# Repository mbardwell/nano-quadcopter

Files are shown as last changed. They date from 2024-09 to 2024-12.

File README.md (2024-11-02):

# Nano Quadcopter Project

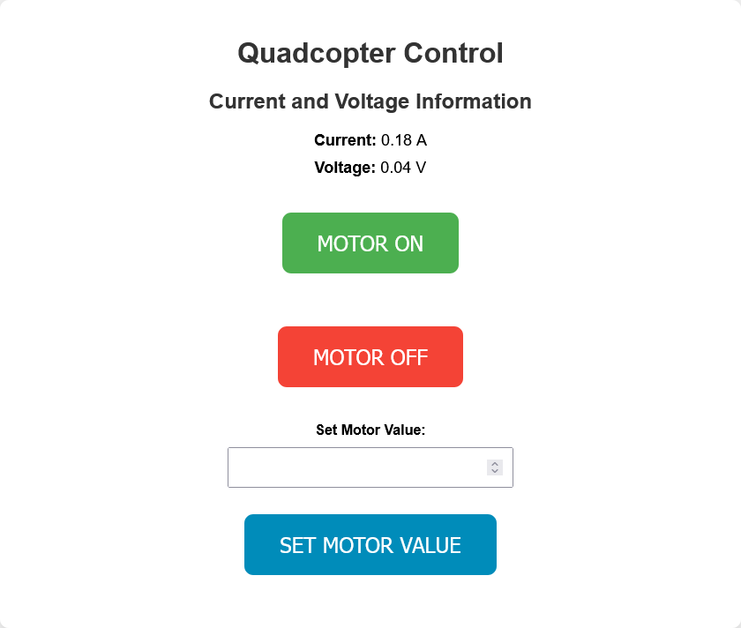
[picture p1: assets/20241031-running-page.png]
Web browser interface

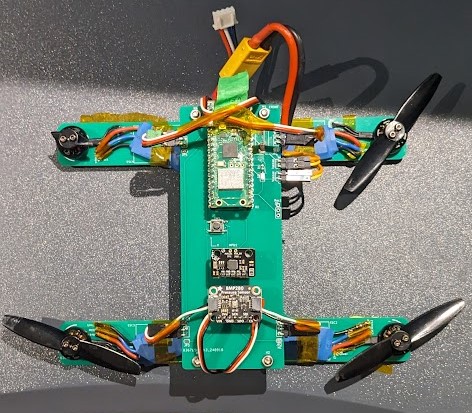
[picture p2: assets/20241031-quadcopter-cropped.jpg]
Nano Quadcopter


## Overview

Welcome to the Nano Quadcopter project! This repository contains all the necessary files and instructions to build and program your own nano quadcopter.

The repository is in such a state that it would be better used as source code than an instruction manual.

This project is heavily inspired by Carbon Aeronautic's drone series [YT](https://www.youtube.com/@carbonaeronautics).

## Features

- Compact and lightweight design
- Easy to assemble
- Customizable firmware
- Open-source hardware and software

## Getting Started

### Prerequisites

- KiCad installed
- Arduino installed
- Electronics and soldering equipment

## License

This project is licensed under a standard MIT License.

## Contact

For any questions or feedback, please open an issue or contact us at [github.com.casually782@passinbox.com](mailto:github.com.casually782@passinbox.com).

Happy flying!

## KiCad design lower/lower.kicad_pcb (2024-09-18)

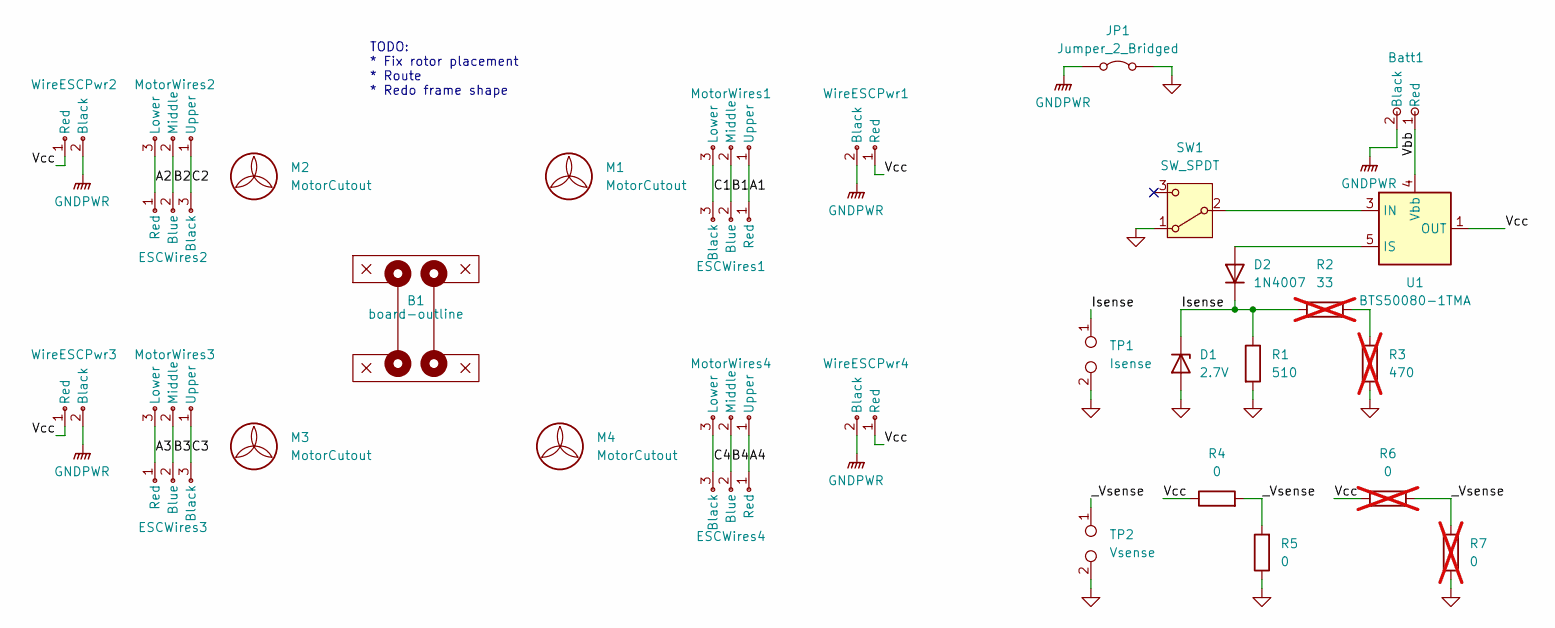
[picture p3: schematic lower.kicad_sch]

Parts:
B1: board-outline; board-outline-test
Batt1: WireBatt
D1: 2.7V; D_T-1_P5.08mm_Horizontal
D2: 1N4007; D_DO-41_SOD81_P10.16mm_Horizontal
ESCWires1, ESCWires2, ESCWires3, ESCWires4: WireESC
H1, H2, H3, H4: MountingHole; MountingHole_3.2mm_M3_ISO14580
JP1: Jumper_2_Bridged; SolderJumperLarge
M1, M2, M3, M4: MotorCutout; MotorEdges
MotorWires1, MotorWires2, MotorWires3, MotorWires4: WireMotor
R1: 510; R_0201_0603Metric_Pad0.64x0.40mm_HandSolder
R2: 33; R_Axial_DIN0207_L6.3mm_D2.5mm_P7.62mm_Horizontal; not fitted
R3: 470; R_Axial_DIN0207_L6.3mm_D2.5mm_P7.62mm_Horizontal; not fitted
R4, R5: 0; R_1206_3216Metric_Pad1.30x1.75mm_HandSolder
R6, R7: 0; R_Axial_DIN0207_L6.3mm_D2.5mm_P7.62mm_Horizontal; not fitted
SW1: SW_SPDT; SW_Slide_SPDT_Angled_CK_OS102011MA1Q
TP1: Isense; TestPoint_2Pads_Pitch2.54mm_Drill0.8mm
TP2: Vsense; TestPoint_2Pads_Pitch2.54mm_Drill0.8mm
U1: BTS50080-1TMA; TO-263-7_TabPin4
WireESCPwr1, WireESCPwr2, WireESCPwr3, WireESCPwr4: WireESCPwr

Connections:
/A1: ESCWires1.1 (Red), MotorWires1.1 (Upper)
/A2: ESCWires2.1 (Red), MotorWires2.3 (Lower)
/A3: ESCWires3.1 (Red), MotorWires3.3 (Lower)
/A4: ESCWires4.1 (Red), MotorWires4.1 (Upper)
/B1: ESCWires1.2 (Blue), MotorWires1.2 (Middle)
/B2: ESCWires2.2 (Blue), MotorWires2.2 (Middle)
/B3: ESCWires3.2 (Blue), MotorWires3.2 (Middle)
/B4: ESCWires4.2 (Blue), MotorWires4.2 (Middle)
/C1: ESCWires1.3 (Black), MotorWires1.3 (Lower)
/C2: ESCWires2.3 (Black), MotorWires2.1 (Upper)
/C3: ESCWires3.3 (Black), MotorWires3.1 (Upper)
/C4: ESCWires4.3 (Black), MotorWires4.3 (Lower)
/Isense: D1.1 (K), D2.1 (K), R1.1, R2.1, TP1.1
/Vbb: Batt1.1 (Red), U1.4 (Vbb)
/Vcc: R4.1, R6.1, U1.1 (OUT), U1.2 (OUT), U1.6 (OUT), U1.7 (OUT), WireESCPwr1.1 (Red), WireESCPwr2.1 (Red), WireESCPwr3.1 (Red), WireESCPwr4.1 (Red)
/_Vsense: R4.2, R5.2, R6.2, R7.1, TP2.1
GND: D1.2 (A), JP1.2 (B), R1.2, R3.2, R5.1, R7.2, SW1.1 (A), TP1.2, TP2.2
GNDPWR: Batt1.2 (Black), JP1.1 (A), WireESCPwr1.2 (Black), WireESCPwr2.2 (Black), WireESCPwr3.2 (Black), WireESCPwr4.2 (Black)
unnamed: D2.2 (A), U1.5 (IS)
unnamed: R2.2, R3.1
unnamed: SW1.2 (B), U1.3 (IN)

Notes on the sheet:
TODO: * Fix rotor placement * Route * Redo frame shape

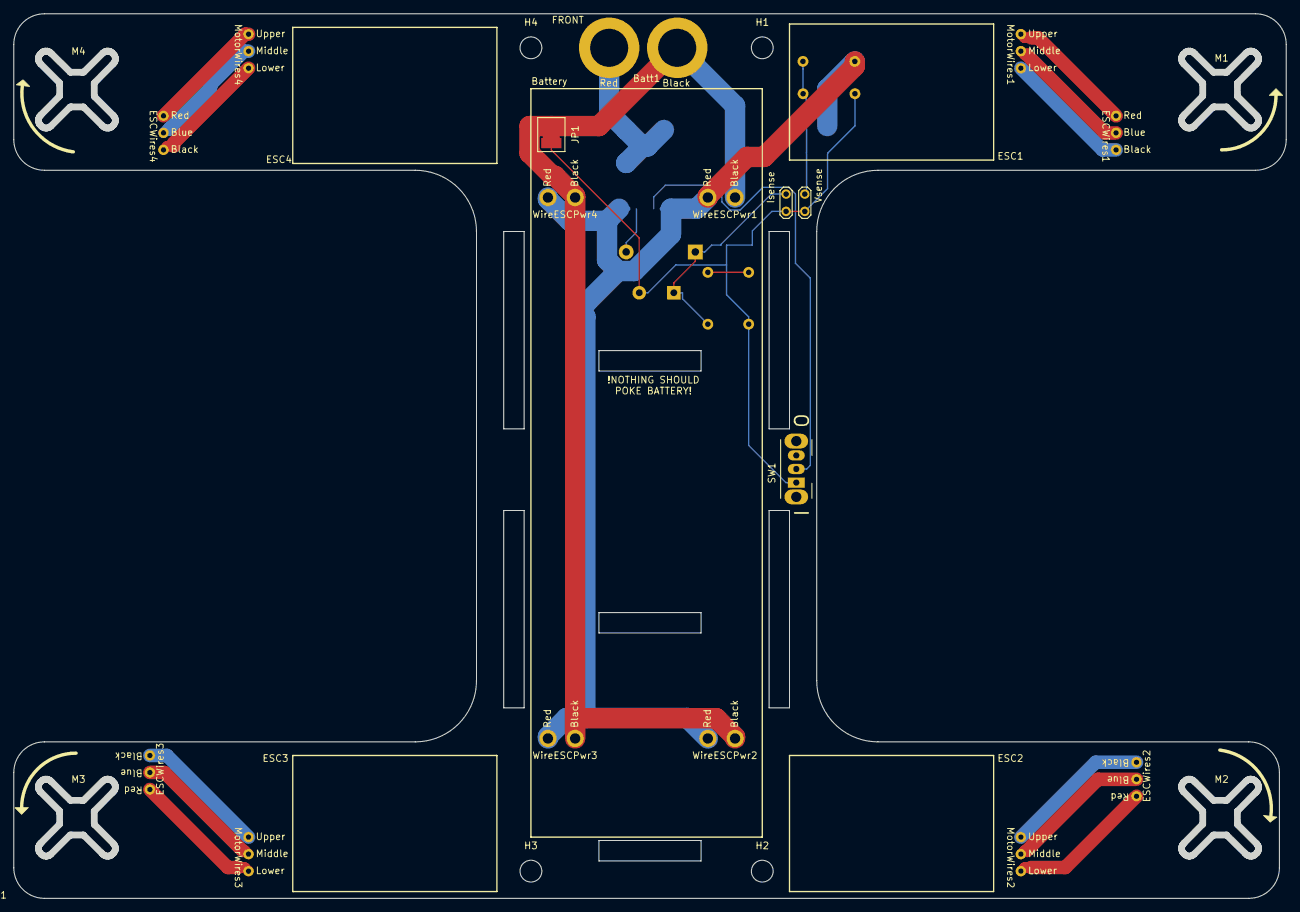
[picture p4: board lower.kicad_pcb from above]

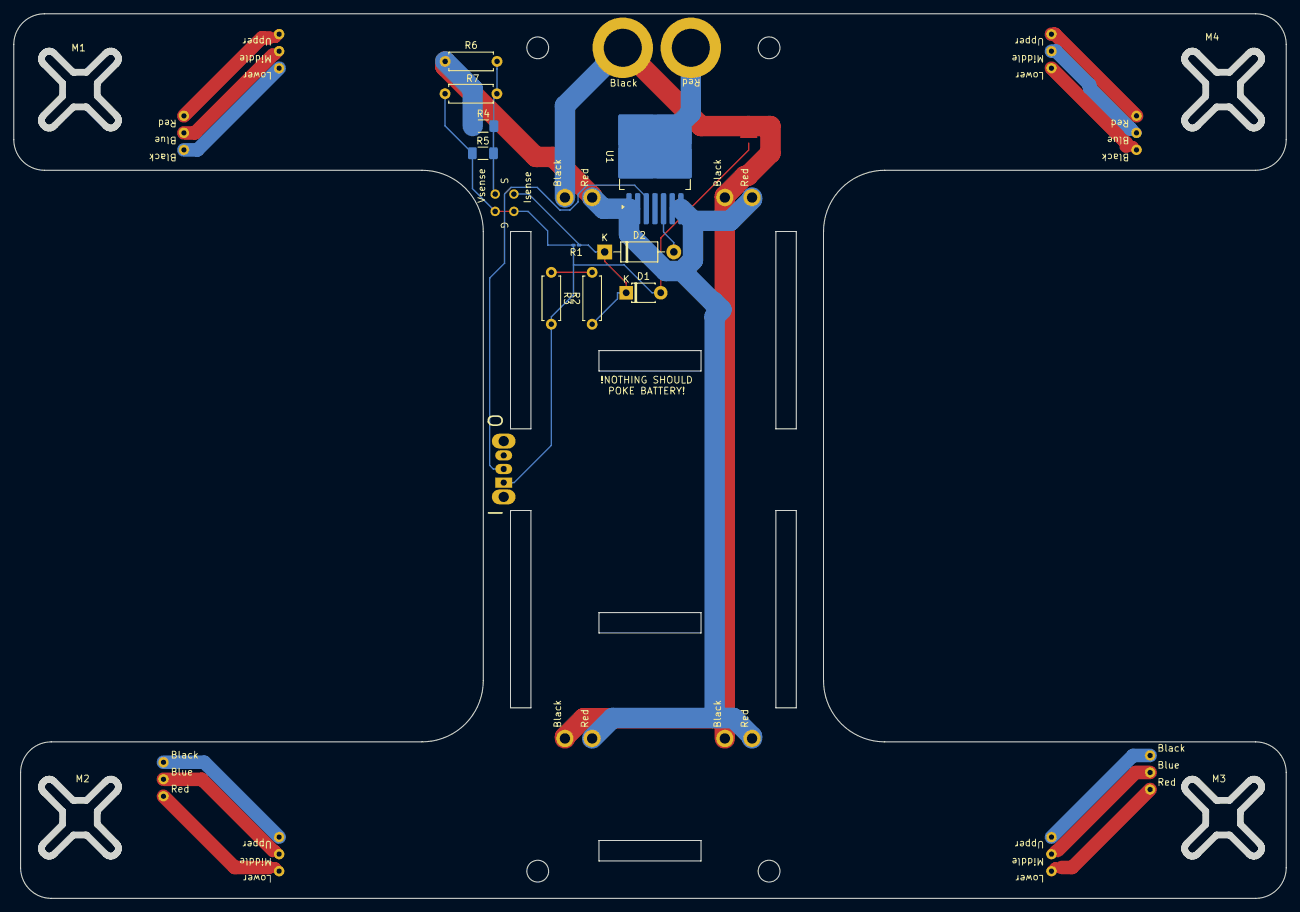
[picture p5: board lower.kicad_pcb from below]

Board: 2 copper layers, 187.0 x 130.0 mm, 36 parts (10 on the bottom side), 21 nets.

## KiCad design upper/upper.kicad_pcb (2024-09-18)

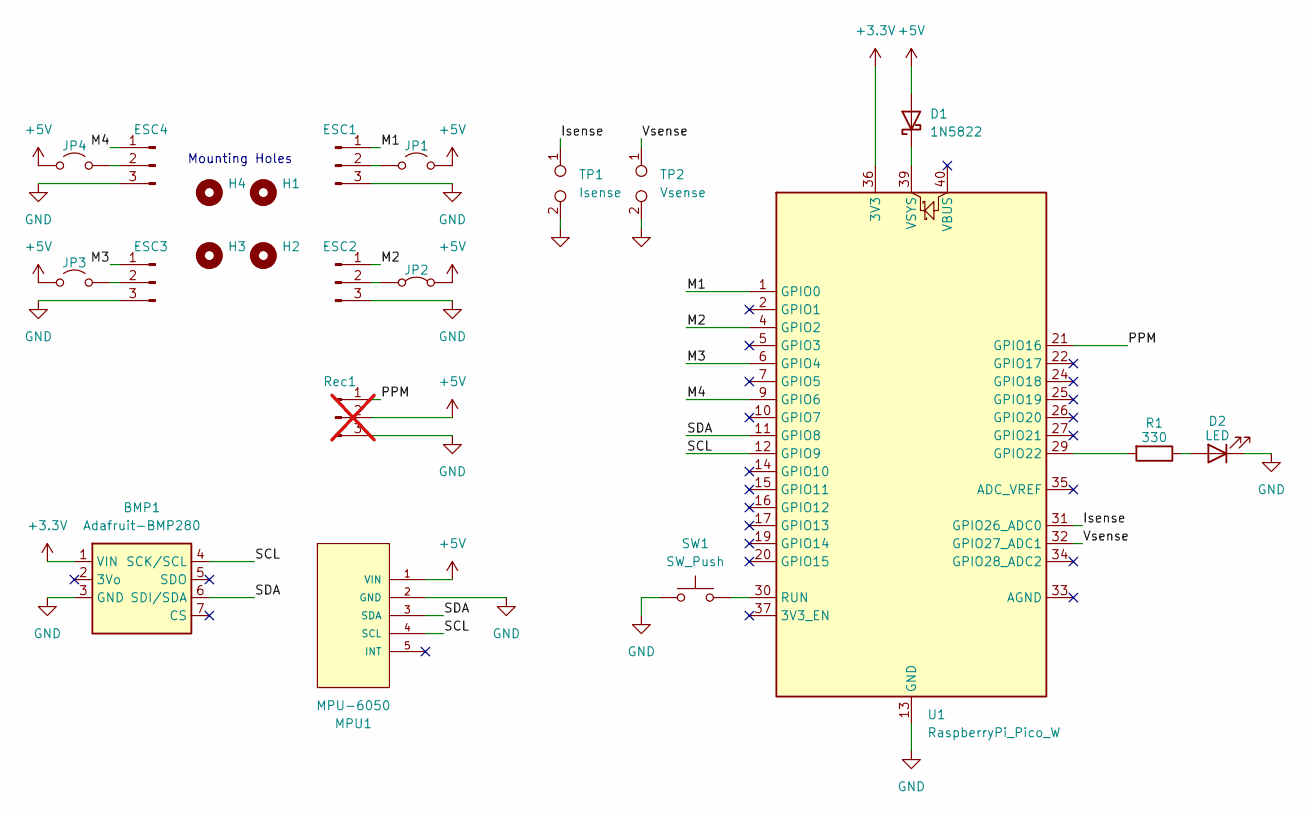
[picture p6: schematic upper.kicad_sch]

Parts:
BMP1: Adafruit-BMP280; adafruit-bmp280
D1: 1N5822; D_SMC_Handsoldering
D2: LED; LED_1206_3216Metric_Pad1.42x1.75mm_HandSolder
ESC1, ESC2, ESC3, ESC4: PinHeader_1x03_P2.54mm_Vertical
H1, H2, H3, H4: MountingHole; MountingHole_3.2mm_M3_ISO14580
JP1, JP3, JP4: Jumper_2_Open; SolderJumper-2_P1.3mm_Open_RoundedPad1.0x1.5mm
JP2: Jumper_2_Bridged; SolderJumper-2_P1.3mm_Bridged_RoundedPad1.0x1.5mm
MPU1: MPU-6050; SEN0142
R1: 330; R_0805_2012Metric_Pad1.20x1.40mm_HandSolder
Rec1: PinHeader_1x03_P2.54mm_Vertical; not fitted
SW1: SW_Push; SW_Push_1P1T_NO_6x6mm_H9.5mm
TP1: Isense; TestPoint_2Pads_Pitch2.54mm_Drill0.8mm
TP2: Vsense; TestPoint_2Pads_Pitch2.54mm_Drill0.8mm
U1: RaspberryPi_Pico_W; RaspberryPi_Pico_Common

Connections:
+3.3V: BMP1.1 (VIN), U1.36 (3V3)
+5V: D1.2 (A), JP1.2 (B), JP2.2 (B), JP3.1 (A), JP4.1 (A), MPU1.1 (VIN), Rec1.2
/Isense: TP1.1, U1.31 (GPIO26_ADC0)
/M1: ESC1.1, U1.1 (GPIO0)
/M2: ESC2.1, U1.4 (GPIO2)
/M3: ESC3.1, U1.6 (GPIO4)
/M4: ESC4.1, U1.9 (GPIO6)
/PPM: Rec1.1, U1.21 (GPIO16)
/SCL: BMP1.4 (SCK/SCL), MPU1.4 (SCL), U1.12 (GPIO9)
/SDA: BMP1.6 (SDI/SDA), MPU1.3 (SDA), U1.11 (GPIO8)
/Vsense: TP2.1, U1.32 (GPIO27_ADC1)
GND: BMP1.3 (GND), D2.1 (K), ESC1.3, ESC2.3, ESC3.3, ESC4.3, MPU1.2 (GND), Rec1.3, SW1.1, TP1.2, TP2.2, U1.3 (GND), U1.8 (GND), U1.13 (GND), U1.18 (GND), U1.23 (GND), U1.28 (GND), U1.38 (GND)
unnamed: D1.1 (K), U1.39 (VSYS)
unnamed: D2.2 (A), R1.1
unnamed: ESC1.2, JP1.1 (A)
unnamed: ESC2.2, JP2.1 (A)
unnamed: ESC3.2, JP3.2 (B)
unnamed: ESC4.2, JP4.2 (B)
unnamed: R1.2, U1.29 (GPIO22)
unnamed: SW1.2, U1.30 (RUN)

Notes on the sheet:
Mounting Holes

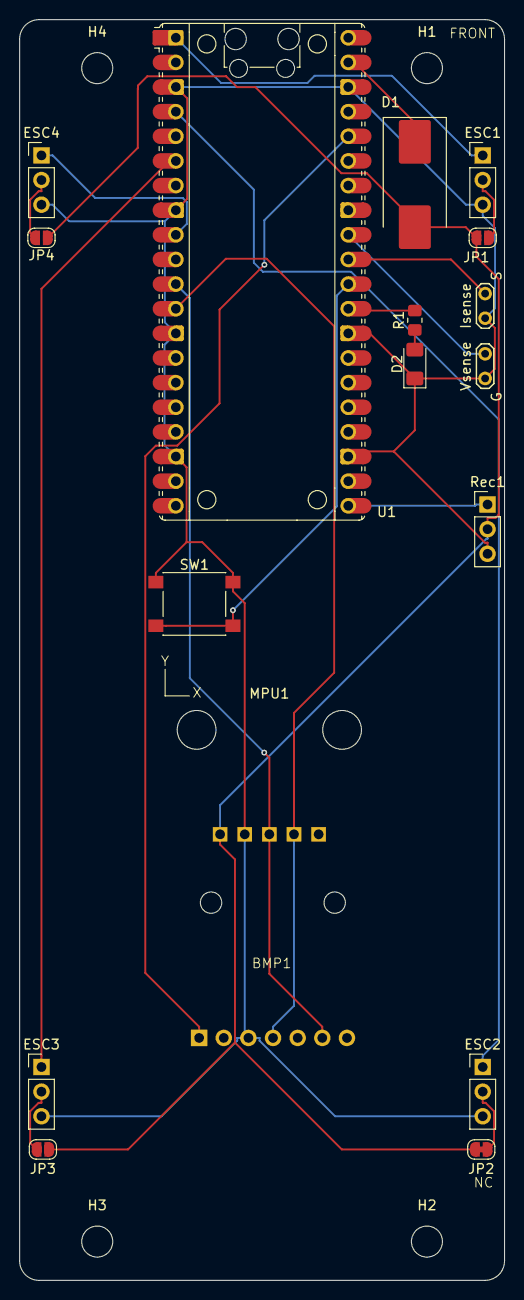
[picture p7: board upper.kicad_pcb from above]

Board: 2 copper layers, 50.0 x 130.0 mm, 22 parts (0 on the bottom side), 20 nets.

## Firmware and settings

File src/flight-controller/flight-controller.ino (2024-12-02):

/**
 * @file flight-controller.ino
 * @brief Flight controller for a nano quadcopter project using various sensors and WiFi communication.
 * 
 * This nano quadcopter flight controller handles motor signals, sensor data acquisition,
 * and WiFi communication for remote control and telemetry. It includes PID control for 
 * stabilizing the quadcopter based on IMU and pressure sensor data.
 * 
 * When turned on, the quadcopter will create a WiFi network with the name in WIFI_SSID below.
 * Join that, then open a browser and go to 192.168.42.1:4242 to access the control interface.
 * 
 * @details
 * The flight controller includes the following functionalities:
 * - IMU setup and calibration
 * - Pressure sensor setup and altitude calculation
 * - Power monitoring setup and signal processing
 * - WiFi setup and signal processing
 * - Motor control and emergency handling
 * - PID control for roll, pitch, and yaw stabilization
 * 
 * The main loop handles sensor data acquisition, user input processing, PID calculations,
 * and motor signal updates. It also manages emergency states and logs telemetry data.
 * 
 * @note
 * - Ensure the correct wiring of sensors and motors.
 * - Adjust PID coefficients and other constants as needed for your specific quadcopter.
 * - The WiFi SSID and port are hardcoded and should be updated as necessary.
 * 
 * @section Dependencies
 * - Adafruit BMP280 library
 * - CircularBuffer library
 * - Servo library
 * - WiFi library
 * - Wire library
 * 
 * @section Pin Configuration
 * - Motor pins: PIN_M1, PIN_M2, PIN_M3, PIN_M4
 * - I2C pins: PIN_I2C_SDA, PIN_I2C_SCL
 * - LED pins: PIN_LED_MOTOR, PIN_LED_EMERGENCY
 * - Power monitoring pins: PIN_IMON, PIN_VMON
 * 
 * @section Constants
 * - WiFi SSID: WIFI_SSID
 * - WiFi port: WIFI_PORT
 * - Emergency kill timeout: EMERGENCY_KILL_MS
 * - Throttle and ESC limits: THROTTLE_MAX, THROTTLE_IDLE, THROTTLE_MIN, ESC_MAX, ESC_MIN
 * - PID coefficients: kPidCoeffs
 * 
 * @section Structures
 * - Motor: Stores motor signal values.
 * - Pid: Stores PID coefficients.
 * - Rpy: Template structure for roll, pitch, and yaw values.
 * - UserInput: Stores user input values for roll, pitch, yaw, throttle, and motor state.
 * - BmpData: Stores BMP280 sensor data and calculates altitude.
 * - Telemetry: Stores telemetry data for logging.
 * 
 * @section Functions
 * - setup: Initializes all components and sensors.
 * - loop: Main loop handling sensor data, user input, PID control, and motor signals.
 * - imu_setup: Initializes the IMU.
 * - imu_calibration: Calibrates the IMU.
 * - imu_signals: Reads IMU signals.
 * - pressure_setup: Initializes the pressure sensor.
 * - altitude_calibration: Calibrates the altitude.
 * - pressure_signals: Reads pressure sensor signals.
 * - pmon_setup: Initializes power monitoring.
 * - pmon_signals: Reads power monitoring signals.
 * - wifi_setup: Initializes WiFi.
 * - wifi_signals: Processes WiFi signals and user input.
 * - wifi_state_emergency: Handles WiFi signals during emergency state.
 * - motor_setup: Initializes motors.
 * - motor_signals: Updates motor signals.
 * - motor_off: Turns off motors.
 * - angular_rate_of_input: Calculates angular rate from user input.
 * - calculate_motor_signals: Calculates motor signals based on throttle and PID output.
 * - pid_equation: Calculates PID output.
 * - pid_reset: Resets PID memory.
 */
// 

#include <Adafruit_BMP280.h>
#include <CircularBuffer.hpp>
#include <cmath>
#include <Servo.h>
#include <WiFi.h>
#include <Wire.h>

#include "html.hpp"

constexpr pin_size_t PIN_M1 = 0;
constexpr pin_size_t PIN_M2 = 2;
constexpr pin_size_t PIN_M3 = 4;
constexpr pin_size_t PIN_M4 = 6;
constexpr pin_size_t PIN_I2C_SDA = 8;
constexpr pin_size_t PIN_I2C_SCL = 9;
constexpr pin_size_t PIN_LED_MOTOR = 22;
constexpr pin_size_t PIN_LED_EMERGENCY = PIN_LED;
constexpr pin_size_t PIN_IMON = A0;
constexpr pin_size_t PIN_VMON = A1;
constexpr byte I2C_ADDRESS_MPU = 0x68;
constexpr char WIFI_SSID[] = "FBI-surveillance-van";
constexpr unsigned WIFI_PORT = 4242;
constexpr unsigned EMERGENCY_KILL_MS = 60000;
constexpr unsigned THROTTLE_MAX = 1800;  // Throttle max must leave headroom for roll, pitch, yaw-ing at max throttle
constexpr unsigned THROTTLE_IDLE = 1180;
constexpr unsigned THROTTLE_MIN = 1000;
constexpr float RPY_MAX = 2000.0;
constexpr float RPY_DEFAULT = 1500.0;
constexpr float RPY_MIN = 1000.0;
constexpr unsigned ESC_MAX = 2000;
constexpr unsigned ESC_MIN = 1000;

Servo m1_esc, m2_esc, m3_esc, m4_esc;
Adafruit_BMP280 bmp;
Adafruit_Sensor *bmp_temp = bmp.getTemperatureSensor();
Adafruit_Sensor *bmp_pressure = bmp.getPressureSensor();
float current, voltage;
sensors_event_t temp_event, pressure_event;
WiFiServer server(WIFI_PORT);
struct Motor {
  unsigned one = ESC_MIN;
  unsigned two = ESC_MIN;
  unsigned three = ESC_MIN;
  unsigned four = ESC_MIN;
};
int last_contact = 0;
struct Pid {
  float p = 0.0;
  float i = 0.0;
  float d = 0.0;
};
/**
 * @brief A template structure representing Roll, Pitch, and Yaw (RPY) values.
 * 
 * Roll, pitch, and yaw directions are defined as follows:
 * - Roll: +ve is clockwise (CW) rotation around the X-axis.
 * - Pitch: +ve is clockwise (CW) rotation around the Y-axis.
 * - Yaw: +ve is clockwise (CW) rotation around the Z-axis.
 * 
 * @tparam T The data type of the roll, pitch, and yaw values (e.g., float, double).
 */
template<typename T>
struct Rpy {
  T roll;
  T pitch;
  T yaw;

  Rpy() = default;
  Rpy(T r, T p, T y) : roll(r), pitch(p), yaw(y) {};

  Rpy<T> operator+(const Rpy<T> &rhs) const {
    return {roll + rhs.roll, pitch + rhs.pitch, yaw + rhs.yaw};
  }

  Rpy<T> operator-(const Rpy<T> &rhs) const {
    return {roll - rhs.roll, pitch - rhs.pitch, yaw - rhs.yaw};
  }

  bool operator==(const Rpy<T> &rhs) const {
    return roll == rhs.roll && pitch == rhs.pitch && yaw == rhs.yaw;
  }
};
struct UserInput {
  Rpy<float> rpy;
  Rpy<Pid> &pid_coeffs;
  Rpy<bool> rpy_on;
  float throttle;
  bool on;

  void print() const {
    Serial.printf("User Input: Roll=%.2f, Pitch=%.2f, Yaw=%.2f, Throttle=%.2f, Roll On=%s, Pitch On=%s, Yaw On=%s, Motor On=%s\n",
                  rpy.roll, rpy.pitch, rpy.yaw, throttle, rpy_on.roll ? "true" : "false", rpy_on.pitch ? "true" : "false", rpy_on.yaw ? "true" : "false", on ? "true" : "false");
  }
};
struct BmpData {
  float temp;
  float pressure;
  float altitude;
  float altitude_cal;
  bool altitude_cal_set;

  BmpData() : temp(0.0), pressure(0.0), altitude(0.0), altitude_cal(0.0), altitude_cal_set(false) {}

  float calculate_altitude() {
    // Baseline pressure and temperature changes throughout the day
    // This value needs to be paired with a calibration value to be accurate
    constexpr float ATM_PRESSURE_BASELINE = 1013.25;
    altitude = 44330 * (1 - (pow(pressure / ATM_PRESSURE_BASELINE, 1/5.255))) - altitude_cal;
    return altitude;
  }

  void print() const {
    Serial.printf("Temperature: %.2f, Pressure: %.2f, Altitude: %.2f\n", temp, pressure, altitude);
  }
};

struct Telemetry {
  unsigned long time;
  float throttle;
  Rpy<float> input, desired, raw, error, pid;
  Motor motor;
  float voltage;
  float current;
};
CircularBuffer<Telemetry, 1800> telemetry_store;

void imu_setup();
bool imu_calibration(Rpy<float> &);
bool imu_signals(const Rpy<float> &, Rpy<float> &);
void pressure_setup();
bool altitude_calibration(float &);
bool pressure_signals(BmpData &);
void pmon_setup();
bool pmon_signals();
void wifi_setup();
bool wifi_signals(UserInput &, bool &, const WebInterfaceData &);
void wifi_state_emergency(bool &, const WebInterfaceData &);
void motor_setup();
void motor_signals(const Motor &);
void motor_off();
Rpy<float> angular_rate_of_input(const Rpy<float> &);
float pid_equation(const Pid, float, float &, float &);
void pid_reset(Rpy<float> &, Rpy<float> &);
Motor calculate_motor_signals(float, const Rpy<float> &);

void setup() {
  int MAX_HOLD_MS = 2000;
  Serial.begin(115200);
  while (!Serial && (millis() < MAX_HOLD_MS))
    ;

  Wire.setSDA(PIN_I2C_SDA);
  Wire.setSCL(PIN_I2C_SCL);
  Wire.setClock(400000);
  Wire.begin();
  delay(250);

  wifi_setup();
  pmon_setup();
  imu_setup();
  pressure_setup();
  motor_setup();

  pinMode(PIN_LED_MOTOR, OUTPUT);
  pinMode(PIN_LED_EMERGENCY, OUTPUT);
}

void loop() {
  const int PRINT_PERIOD_MS = 5000;
  static int print_hold = 0;
  static bool loop_print = false;
  static Rpy<float> imu_cal, imu_rate, pid_mem_err, pid_mem_iterm;
  static Motor m_values;
  static bool emergency = false;
  static BmpData bmp_data;
  static WebInterfaceData web_data;
  static Rpy<Pid> pid_coeffs = {
    {0.6, 0.001, 0.03},
    {0.3, 0.001, 0.03},
    {1.0, 0.005, 0},
  };
  static UserInput user_input = {
    Rpy<float>(RPY_DEFAULT, RPY_DEFAULT, RPY_DEFAULT), 
    pid_coeffs,
    Rpy<bool>{true, true, true},
    THROTTLE_IDLE,
    false
    };

  // Keep this at the top
  if (emergency) {
    user_input.on = false;
    motor_off();
    wifi_state_emergency(emergency, web_data);
    digitalWrite(PIN_LED_EMERGENCY, HIGH);
    return;
  }
  digitalWrite(PIN_LED_EMERGENCY, LOW);

  if (imu_cal == Rpy<float>()) {
    web_data.imu_cal = imu_calibration(imu_cal);
  }

  if (!bmp_data.altitude_cal_set) {
    web_data.alt_cal = altitude_calibration(bmp_data.altitude_cal);
    bmp_data.altitude_cal_set = true;
  }

  if ((millis() - print_hold) > PRINT_PERIOD_MS) {
    loop_print = true;
    print_hold = millis();
  }

  if (pmon_signals() && loop_print) {
    Serial.print("Voltage [V]= ");
    Serial.print(voltage);
    Serial.print(" Current [A]= ");
    Serial.println(current);
    web_data.V = voltage;
    web_data.I = current;
  }

  if (imu_signals(imu_cal, imu_rate) && loop_print) {
    Serial.printf("Roll rate [°/s]=%.2f, Pitch rate [°/s]=%.2f, Yaw rate [°/s]=%.2f\n", imu_rate.roll, imu_rate.pitch, imu_rate.yaw);
  }

  if (pressure_signals(bmp_data) && loop_print) {
    bmp_data.print();
    web_data.alt = bmp_data.altitude;
  }

  if (wifi_signals(user_input, emergency, web_data)) {
    user_input.print();
    web_data.roll_p = pid_coeffs.roll.p;
    web_data.roll_i = pid_coeffs.roll.i;
    web_data.roll_d = pid_coeffs.roll.d;
    web_data.pitch_p = pid_coeffs.pitch.p;
    web_data.pitch_i = pid_coeffs.pitch.i;
    web_data.pitch_d = pid_coeffs.pitch.d;
    web_data.yaw_p = pid_coeffs.yaw.p;
    web_data.yaw_i = pid_coeffs.yaw.i;
    web_data.yaw_d = pid_coeffs.yaw.d;
  }

  user_input.throttle = min(max(user_input.throttle, THROTTLE_MIN), THROTTLE_MAX);
  Rpy<float> desired = angular_rate_of_input(user_input.rpy);
  Rpy<float> error = desired - imu_rate;
  Rpy<float> pid_out;
  pid_out.roll = user_input.rpy_on.roll ? pid_equation(pid_coeffs.roll, error.roll, pid_mem_err.roll, pid_mem_iterm.roll) : 0;
  pid_out.pitch = user_input.rpy_on.pitch ? pid_equation(pid_coeffs.pitch, error.pitch, pid_mem_err.pitch, pid_mem_iterm.pitch) : 0;
  pid_out.yaw = user_input.rpy_on.yaw ? pid_equation(pid_coeffs.yaw, error.yaw, pid_mem_err.yaw, pid_mem_iterm.yaw) : 0;
  if (loop_print) {
    Serial.printf("PID Output: Roll=%.2f, Pitch=%.2f, Yaw=%.2f\n", pid_out.roll, pid_out.pitch, pid_out.yaw);
  }
  static unsigned first_five = 5;
  if (user_input.on) {
    if (first_five > 0) {
      const unsigned PULSE_LOW = ESC_MIN + 50;
      motor_signals({PULSE_LOW, PULSE_LOW, PULSE_LOW, PULSE_LOW});
      first_five--;
    }
    else {
      m_values = calculate_motor_signals(user_input.throttle, pid_out);
      motor_signals(m_values);
    }
  }
  else {
    motor_off();
    pid_reset(pid_mem_err, pid_mem_iterm);
    first_five = 5;
  }

  if (!emergency) {
    telemetry_store.push(
    {millis(), 
    user_input.throttle, 
    user_input.rpy,
    desired,
    imu_rate,
    error,
    pid_out,
    m_values,
    voltage,
    current}
    );
  }
  loop_print = false;
}

void pmon_setup() {
  pinMode(PIN_IMON, INPUT);
  pinMode(PIN_VMON, INPUT);
}

bool pmon_signals() {
  const float VMAX = 3.3;
  const float ADC_MAX = 1023.0;
  const int BTS_RATIO = 14000;
  const int LOWER_R1 = 503;
  const int LOWER_R4 = 1000;
  const int LOWER_R5 = 330;
  static int _voltage, _current;
  _current = analogRead(PIN_IMON);
  _voltage = analogRead(PIN_VMON);
  current = _current * (VMAX / ADC_MAX) * BTS_RATIO / LOWER_R1;
  voltage = _voltage * (VMAX / ADC_MAX) * ((LOWER_R4 + LOWER_R5) / (LOWER_R5));
  return true;
}

void imu_setup() {
  Wire.beginTransmission(I2C_ADDRESS_MPU);
  Wire.write(0x75); // WHO_AM_I register
  Wire.endTransmission();
  Wire.requestFrom(I2C_ADDRESS_MPU, 1);
  if (Wire.available()) {
    byte who_am_i = Wire.read();
    if (who_am_i != 0x68) {
      Serial.printf("Unexpected WHO_AM_I value: 0x%02X\n", who_am_i);
      return;
    }
  }
  Wire.beginTransmission(I2C_ADDRESS_MPU);
  Wire.write(0x6B); // PWR Management 1
  Wire.write(0x01); // Change clock source from default as recommended
  Wire.endTransmission();
  Wire.beginTransmission(I2C_ADDRESS_MPU);
  Wire.write(0x1A); // LPF
  Wire.write(0x06); // [value,BW Hz]: [4,21],[5,10],[6,5]
  Wire.endTransmission();
  Wire.beginTransmission(I2C_ADDRESS_MPU);
  Wire.write(0x1B); // Gyro Config
  Wire.write(0x08); // FSR +/- 500 deg/s
  Wire.endTransmission();
  delay(250);
}

bool imu_calibration(Rpy<float> &cal) {
  const unsigned N = 2000;
  unsigned n_fail = 0;
  Rpy<float> r_sum, r_once;
  for (unsigned i = 0; i < N; ++i) {
    if (!imu_signals(Rpy<float>(), r_once)) {
      if (++n_fail > 10)
        return false;
      continue;
    }
    r_sum = r_once + r_sum;
    delay(1);
  }
  cal.roll = r_sum.roll / static_cast<float>(N);
  cal.pitch = r_sum.pitch / static_cast<float>(N);
  cal.yaw = r_sum.yaw / static_cast<float>(N);
  Serial.printf("IMU Calibration. Roll: %.2f Pitch: %.2f Yaw: %.2f\n", cal.roll, cal.pitch, cal.yaw);
  return true;
}

bool imu_signals(const Rpy<float> &cal, Rpy<float> &gyro) {
  const float LSB_PER_DEG_PER_S = 65.5;
  Wire.beginTransmission(I2C_ADDRESS_MPU);
  Wire.write(0x43); // Point to Gyro Data. May want to call this in the loop
  Wire.endTransmission();
  if (Wire.requestFrom(I2C_ADDRESS_MPU, 6) != 6) {
    Serial.println("Warning: Failed to request from MPU");
    return false;
  }
  int timeout = 50;
  while (Wire.available() < 6 && timeout-- != 0)
    delay(1);
  int16_t raw_x = (Wire.read() << 8) | Wire.read();
  int16_t raw_y = (Wire.read() << 8) | Wire.read();
  int16_t raw_z = (Wire.read() << 8) | Wire.read();
  gyro.roll = (static_cast<float>(raw_x) / LSB_PER_DEG_PER_S) - cal.roll;
  gyro.pitch = (static_cast<float>(raw_y) / LSB_PER_DEG_PER_S) - cal.pitch;
  gyro.yaw = (static_cast<float>(raw_z) / LSB_PER_DEG_PER_S) - cal.yaw;
  return true;
}

void pressure_setup() {
  unsigned status = bmp.begin();
  if (!status) {
    Serial.println(F("Could not find a valid BMP280 sensor, check wiring or "
                     "try a different address!"));
    Serial.print("SensorID was: 0x");
    Serial.println(bmp.sensorID(), 16);
    Serial.print("        ID of 0xFF probably means a bad address, a BMP 180 or BMP 085\n");
    Serial.print("   ID of 0x56-0x58 represents a BMP 280,\n");
    Serial.print("        ID of 0x60 represents a BME 280.\n");
    Serial.print("        ID of 0x61 represents a BME 680.\n");
    while (1) delay(10);
  }
  /* Default settings from datasheet. */
  bmp.setSampling(Adafruit_BMP280::MODE_NORMAL,     /* Operating Mode. */
                  Adafruit_BMP280::SAMPLING_X2,     /* Temp. oversampling */
                  Adafruit_BMP280::SAMPLING_X16,    /* Pressure oversampling */
                  Adafruit_BMP280::FILTER_X16,      /* Filtering. */
                  Adafruit_BMP280::STANDBY_MS_500); /* Standby time. */
  bmp_temp->printSensorDetails();
}

bool altitude_calibration(float &alt_cal) {
  const unsigned N = 2000;
  unsigned n_fail = 0;
  BmpData once;
  float sum = 0.0;
  for (unsigned i = 0; i < N; ++i) {
    if (!pressure_signals(once)) {
      if (++n_fail > 10)
        return false;
      continue;
    }
    sum = once.calculate_altitude() + sum;
    delay(1);
  }
  alt_cal = sum / static_cast<float>(N);
  Serial.printf("Altitude Calibration: %.2f\n", alt_cal);
  return true;
}

bool pressure_signals(BmpData &data) {
  if (bmp_temp->getEvent(&temp_event) && bmp_pressure->getEvent(&pressure_event)) {
    data.temp = temp_event.temperature;
    data.pressure = pressure_event.pressure;
    static_cast<void>(data.calculate_altitude());
    return true;
  }
  return false;
}

void motor_setup() {
  m1_esc.attach(PIN_M1);
  m2_esc.attach(PIN_M2);
  m3_esc.attach(PIN_M3);
  m4_esc.attach(PIN_M4);
  motor_off();
  delay(3000);
}

void motor_signals(const Motor &value) {
  auto clamp_motor_values = [](unsigned val) -> unsigned {
    return std::min(std::max(val, ESC_MIN), ESC_MAX);
  };

  m1_esc.writeMicroseconds(clamp_motor_values(value.one));
  m2_esc.writeMicroseconds(clamp_motor_values(value.two));
  m3_esc.writeMicroseconds(clamp_motor_values(value.three));
  m4_esc.writeMicroseconds(clamp_motor_values(value.four));
  digitalWrite(PIN_LED_MOTOR, HIGH);
  static int anti_spam = 0;
  if ((millis() - anti_spam) > 100) {
    Serial.printf("Setting motors to %d %d %d %d\n", clamp_motor_values(value.one), clamp_motor_values(value.two), clamp_motor_values(value.three), clamp_motor_values(value.four));
    anti_spam = millis();
  }
}

void motor_off() {
  m1_esc.writeMicroseconds(ESC_MIN);
  m2_esc.writeMicroseconds(ESC_MIN);
  m3_esc.writeMicroseconds(ESC_MIN);
  m4_esc.writeMicroseconds(ESC_MIN);
  digitalWrite(PIN_LED_MOTOR, LOW);
  static int anti_spam = 0;
  if ((millis() - anti_spam) > 5000) {
    Serial.println("Motors turned off");
    anti_spam = millis();
  }
}

/**
 * @brief Calculate the angular rate of the input
 * @details The input is a user value from the radio transmitter
 * we need to convert this to an angular rate that the PID controller can use
 * @param input The input from the user
 * @return Rpy<float> The angular rate of the input
 */
Rpy<float> angular_rate_of_input(const Rpy<float> &input) {
  auto calculate_desired = [](float input_value) -> float {
    const float SLOPE = 0.15;  // This correspond to 75°/s at max input
    const float DEFAULT_INPUT = 1500.0;
    return SLOPE * (input_value - DEFAULT_INPUT);
  };

  Rpy<float> desired;
  desired.roll = calculate_desired(input.roll);
  desired.pitch = calculate_desired(input.pitch);
  desired.yaw = calculate_desired(input.yaw);
  return desired;
}

Motor calculate_motor_signals(float throttle, const Rpy<float> &pid_output) {
  Motor m;
  if (throttle < THROTTLE_MIN + 50) {
    m.one = ESC_MIN;
    m.two = ESC_MIN;
    m.three = ESC_MIN;
    m.four = ESC_MIN;
    return m;
  }

  const float MOTOR_WEAK_COMPENSATION = 1.0;
  m.one = MOTOR_WEAK_COMPENSATION * (throttle + pid_output.roll - pid_output.pitch - pid_output.yaw);
  m.two = (throttle - pid_output.roll - pid_output.pitch + pid_output.yaw);
  m.three = (throttle - pid_output.roll + pid_output.pitch - pid_output.yaw);
  m.four = MOTOR_WEAK_COMPENSATION * (throttle + pid_output.roll + pid_output.pitch + pid_output.yaw);

  return m;
}

float pid_equation(const Pid constants, float err, float &prev_err, float &prev_iterm) {
  constexpr float kItermCap = 200;
  constexpr float kDtermCap = 100;
  static unsigned long last_run = 0;
  float p_err, i_err, d_err;
  p_err = constants.p * err;
  if (millis() - last_run > 1) {
    i_err = min(max(prev_iterm + constants.i * (err + prev_err), -kItermCap), kItermCap);
    d_err = min(max(constants.d * (err - prev_err), -kDtermCap), kDtermCap);
    last_run = millis();
  }
  else {
    i_err = prev_iterm;
    d_err = err;
  }
  prev_err = err;
  prev_iterm = i_err;
  return p_err + i_err + d_err;
}

void pid_reset(Rpy<float> &prev_err, Rpy<float> &prev_iterm) {
  prev_err = Rpy<float>();
  prev_iterm = Rpy<float>();
}

void wifi_setup() {
  WiFi.mode(WIFI_AP);
  Serial.printf("Connecting to '%s'\n", WIFI_SSID);
  WiFi.beginAP(WIFI_SSID);
  while (WiFi.status() != WL_CONNECTED) {
    Serial.print(".");
    delay(100);
  }
  Serial.printf("\nConnected to WiFi\n\nConnect to server at %s:%d\n", WiFi.localIP().toString().c_str(), WIFI_PORT);
  server.begin();
}
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

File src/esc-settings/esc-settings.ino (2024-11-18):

/**
 * @file esc-settings.ino
 * @brief ESC (Electronic Speed Controller) settings for a nano quadcopter.
 *
 * This program initializes and controls four ESCs using the Servo library.
 * It sets up serial communication to receive commands for adjusting the throttle.
 *
 * @details Use this script to apply the following non-default settings:
 * - Angle of entrance: High
 * - Startup of motor: Accelerated startup
 * - PWM frequency: 16Hz
 * - Protection mode: Cutoff
 */

#include <Servo.h>

constexpr pin_size_t PIN_M1 = 0; ///< Pin for Motor 1 ESC
constexpr pin_size_t PIN_M2 = 2; ///< Pin for Motor 2 ESC
constexpr pin_size_t PIN_M3 = 4; ///< Pin for Motor 3 ESC
constexpr pin_size_t PIN_M4 = 6; ///< Pin for Motor 4 ESC
Servo m1_esc, m2_esc, m3_esc, m4_esc; ///< Servo objects for each ESC

void setup() {
  Serial.begin(115200);
  while (!Serial)
    ;
  m1_esc.attach(PIN_M1);
  m2_esc.attach(PIN_M2);
  m3_esc.attach(PIN_M3);
  m4_esc.attach(PIN_M4);
}

/**
 * @brief Main loop function to read serial input and adjust throttle accordingly.
 *
 * The throttle is set to 2000 microseconds when the up arrow key is pressed,
 * and to 1000 microseconds when the down arrow key is pressed.
 * The throttle value is sent to all four ESCs.
 */
void loop() {
    static int throttle = 2000;
    if (Serial.available() > 0) {
        byte receivedByte = Serial.read();
        switch (receivedByte) {
            case 0x41: // Up arrow
                Serial.println("Up arrow key pressed");
                throttle = 2000;
                break;
            case 0x42: // Down arrow
                Serial.println("Down arrow key pressed");
                throttle = 1000;
                break;
            case 0x43: // Right arrow
                Serial.println("Right arrow key pressed");
                break;
            case 0x44: // Left arrow
                Serial.println("Left arrow key pressed");
                break;
            default:
                break;
        }
    }
    m1_esc.writeMicroseconds(throttle);
    m2_esc.writeMicroseconds(throttle);
    m3_esc.writeMicroseconds(throttle);
    m4_esc.writeMicroseconds(throttle);
}

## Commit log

2024-09-11 Split into upper and lower projects
    [lower.kicad_pcb, lower.kicad_sch, upper.kicad_pcb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]
2024-09-11 Quick lower PCB for cost estimation
    [lower.kicad_pcb, lower.kicad_sch, upper.kicad_pcb]
2024-09-16 Lower v0.1.0. Pre-routing
    [lower.kicad_pcb, lower.kicad_sch]
2024-09-16 Lower v0.1.1. Pre-routing
    [lower.kicad_pcb, lower.kicad_sch]
2024-09-17 Lower v0.1.2. Pre-routing
    [lower.kicad_pcb, lower.kicad_sch]
2024-09-17 v0.1.2. Routed
    [lower.kicad_pcb]
2024-09-17 Upper v0.0.1. Pre-routed
    [upper.kicad_pcb, upper.kicad_sch]
2024-09-17 Upper v0.1.0. Pre-routed
    [upper.kicad_pcb, upper.kicad_sch]
2024-09-18 Upper/Lower: v0.2.0. Pre-routed
    [lower.kicad_pcb, lower.kicad_sch, upper.kicad_pcb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]
2024-09-18 Upper/Lower: v0.2.0. Routed
    [lower.kicad_pcb, upper.kicad_pcb, upper.kicad_sch]
2024-09-18 Lower: v0.2.1. Routed
    [lower.kicad_pcb]
2024-09-18 Upper: Small file changes
    [upper.kicad_pcb]
2024-09-18 Lower: Small file changes
    [lower.kicad_pcb]
2024-09-30 Upper/Lower: Add post-assembly fixup comments
    [lower.kicad_sch, upper.kicad_sch]
2024-09-30 Firmware: Init power sensing
2024-09-30 Upper/Lower: Add notes
    [lower.kicad_sch, upper.kicad_sch]
2024-09-30 Firmware: Add in motors
2024-10-14 Firmware: Add emergency state reset button
2024-10-14 Firmware: Only turn off motors during emergency
2024-10-14 Firmware: Add IMU calibration step
2024-10-16 Firmware: Roughly cut in PID control
2024-10-17 Firmware: Update fnames to IMU/Pressure
2024-10-17 Firmware: Better Roll/Pitch/Yaw data handling
2024-10-17 Firmware: Decompose motor calculations
2024-10-21 Firmware: Fixed IMU calibration
2024-10-22 Firmware: Added motor off print
2024-10-22 Firmware: Add motor signal handling
2024-10-22 Firmware: Try to fix motor value POST. Still issues, but getting there
2024-10-22 Firmware: Motor values pseudo-updating each loop
2024-11-02 Firmware: Quadcopter responds to input throttle changes
2024-11-02 Lower: Identify CW/CCW propellor in schematics
    From the top down:
    * CCW is 3025
    * CW is 3025R
    [lower.kicad_sch]
2024-11-02 Firmware: Web interface displays I/V/Alt/IMU Cal/Alt Cal
2024-11-02 Firmware: Increase angular rate cutoff to 150. Ignore yaw
2024-11-04 Firmware: Leave headroom for R/P/Y at max throttle
2024-11-04 Firmware: Init download data button
2024-11-06 Firmware: Download button gives 2000 pre-emergency samples
2024-11-07 Firmware: Add roll, pitch, yaw docstring
2024-11-07 Upper: Add to v1 issues list
    [upper.kicad_sch]
2024-11-10 Scripting: Send reset. Plot motor values
2024-11-11 Firmware: Update motor signal calculations. Report raw IMU output
2024-11-11 Firmware: Add roll/pitch/yaw correction on/off user input
2024-11-11 Firmware: Increase yaw P-coeff to 2.0
2024-11-11 Firmware: Remove motor compensation. Reduce pitch and yaw P-coeff
2024-11-11 Firmware: Expose roll/pitch/yaw P-coeff to user
2024-11-11 Firmware: Pulse motor low at start to ensure blades are already spinning
2024-11-11 Firmware: User can change all PID coeffs
2024-11-18 ESC Settings: Control with up/down arrow keys
2024-11-18 ESC Settings: Add docs
2024-11-18 FC: Remove magic terms from PID equation
    KISS
2024-11-18 FC: Reset PID controller memory when motors off
    [flight-controller.ino]
2024-11-25 FC: Move IMU logic to setup function. Tighten LPF from 10->5Hz. Use recommend clock source
    [flight-controller.ino]
2024-12-02 FC: Add missing pitch proportional field on webserver
    [flight-controller.ino]
